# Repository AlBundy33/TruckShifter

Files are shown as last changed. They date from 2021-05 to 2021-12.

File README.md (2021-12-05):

# DIY real truck shifter

Because I'm playng Eurotruck Simulator 2 with my T300 + TH8A I wanted to have a shifter that has buttons for range and splitter.

Because I didn't want to spent over 100EUR for a simple gear stick with two or three buttons I decided to bought a cheap MAN shifter (81326200043) from china (in fact something about 16EUR on Amazon).

After that I've used my multimeter to find out the connections between the pins on the socket.

Later I had to open the shifter and could see the connections.

The TH8A uses an M9x1.25 thread and the shifter provides an M14x1.5 thread - unfortuately I didn't find an adapter to buy.

Luckily a forum-member offerd my to print this adapter from thingiverse.

https://www.thingiverse.com/thing:4827444

# Pinout

This is my numbering according to the colors on the plug.
```
0 (black)   1 (blue)    2 (two wires, green/yellow)
3 (purple)  4 (red)     5 (white)
```
ATTENTION: There is a resistor between red and white (range switch) which has to be removed.
To open the shifter you can carefully remove the plastic-piece (with the printed gears) with a plastic tool (just pull the plastic-piece backwards).

These are the connections between the pins
- comfort shift (top): 0 + 2 (normally closed), 1 + 2 (normally open), 1 + 3 (normally open, only if splitter is closed), 0 + 3 (normally closed, if splitter is closed)
- splitter (side): 2 (green)+ 3 (purple)
- range (front): 4 (red)+ 5 (white)

so i think the wiring could be done like this.
```
2 (green+yellow) + 4 (red) -> GND
1 (blue) -> PIN18 (comfort shift)
3 (purlple) -> PIN19 (splitter)
5 (white) -> PIN20 (range)
```

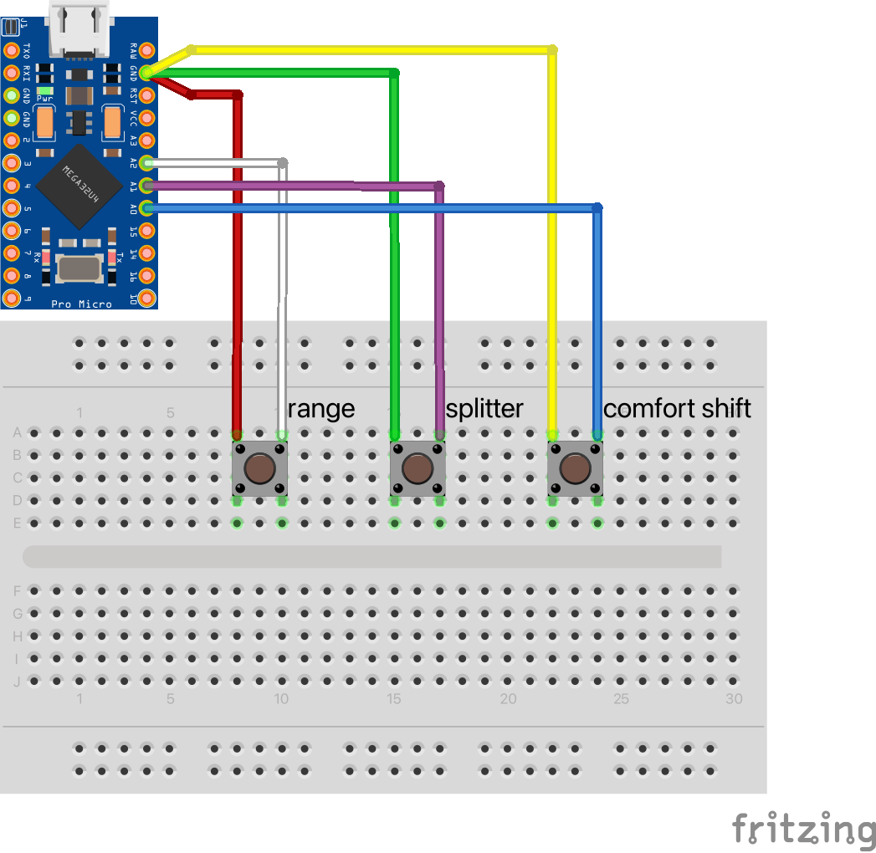
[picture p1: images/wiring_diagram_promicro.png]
wiring diagram (leonardo)

I'm using an arduino pro micro because it fits inside the shifter. :-)

You have to install this library in Arduino IDE: https://github.com/MHeironimus/ArduinoJoystickLibrary

# Pictures
open shifter
inside shifter 1
inside shifter 2
mounted pro micro

Because I have multiple USB devices I had to change the name of the usb device.

Therefore I've edited boards.txt from Arduino IDE and copied the complete block for leonardo.name=Arduino Leonardo

Then I've changed the IDs from "leonardo." to "leonardo_truckshifter." and the name and usb_product from "Arduino Leonardo" to "Arduino Leonardo (TruckShifter)".

As last step I've changed to VID to 0x2341 and the PID to 0xA001.

In the end it looks something like this.
-> This is only an example and for private use only because you have to pay for official/commercial VIDs and PIDs!!!!

HINT: Arduino IDE uses different boards.txt - one is located in your installation-folder under hardware\arduino\avr and the other under %LOCALAPPDATA%\Arduino15\packages\arduino\hardware\avr\1.8.4 (at least on windows - versions may change).

So if there is no "Arduino Leonardo (TruckShifter)" in your boards-list, make sure, that you have edited the correct boards.txt

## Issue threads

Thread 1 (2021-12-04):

Disable LED on pro micro

peer69, 2021-12-04:
By adding

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

to the setup block you can disable the lower LED of the pro micro. It bothered me seeing red light coming from the bottom of the shifter.
The power LED on the upper part cant be turned off in software though afaik, therefore I used some tape over the LED. Disabling the bottom LED and having the pro micro placed facing inwards the shifter might do the trick as well. I just didn't want to rewire it.

AlBundy33, 2021-12-04:
where did you get this information from?

peer69, 2021-12-04:
Been digging through some forum posts yesterday, probably from here: https://arduino.stackexchange.com/questions/3434/leonardo-disable-tx-and-rx-led

Tried it already, works well for me.

AlBundy33, 2021-12-04:
I'm not at the PC right now but have you tried just to call the mentioned macros?
```
TXLED0;
RXLED0;
```

peer69, 2021-12-04:
Yes, did nothing for me. Somebody mentioned this would work by selecting Arduino Micro as board but I haven't tried this after the method I mentioned did the trick. Not sure this is the "best" method to achieve this though.

AlBundy33, 2021-12-05:
in arduino_pins.h the macros are defined as
```
#define TX_RX_LED_INIT	DDRD |= (1<<5), DDRB |= (1<<0)
#define TXLED0			PORTD |= (1<<5)
#define TXLED1			PORTD &= ~(1<<5)
#define RXLED0			PORTB |= (1<<0)
#define RXLED1			PORTB &= ~(1<<0)
```
where TX_RX_LED_INIT sets them as output and your code sets them as input an therefore the LEDs are off.
I've accepted your PR and added some comments. 👍

Closed 2021-12-05.

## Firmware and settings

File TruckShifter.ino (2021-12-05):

#include <Arduino.h>
#include <Joystick.h>

// pins to use
#define COMFORT_SHIFT 18
#define SPLITTER      19
#define RANGE         20

// enable/disable debug-mode (serial output)
// #define DEBUG

// max time to be handled as short press
#define SHORT_PRESS   250

Joystick_ Joystick(JOYSTICK_DEFAULT_REPORT_ID,
                   JOYSTICK_TYPE_JOYSTICK, 4, 0,
                   false, false, false, false, false, false,
                   false, false, false, false, false);

unsigned long cs_press_time = 0L;

void setup() {
    // disable TX and RX LEDs
    // see https://arduino.stackexchange.com/questions/3434/leonardo-disable-tx-and-rx-led
    // and http://forum.arduino.cc/index.php?topic=145262.0
    // TX_RX_LED_INIT; // DDRD |= (1<<5), DDRB |= (1<<0)
    // it seems that TX_RX_LED_INIT makes PORTD5 and PORTB0 output pins
    // but we want to disable them and so we making them to inputs
    DDRD &= ~(1<<DDD5), DDRB &= ~(1<<DDB0);
    // set TX and RX pins to LOW
    TXLED0;
    RXLED0;
    pinMode(COMFORT_SHIFT, INPUT_PULLUP);
    pinMode(SPLITTER, INPUT_PULLUP);
    pinMode(RANGE, INPUT_PULLUP);
    #ifdef DEBUG
    Serial.begin(9600);
    #endif
    Joystick.begin();
}

void loop() {
    int cs = !digitalRead(COMFORT_SHIFT);
    int splitter = !digitalRead(SPLITTER);
    int range = !digitalRead(RANGE);
    unsigned long cs_pressed;

    if (cs == HIGH && cs_press_time == 0L)
        cs_press_time = millis();

    if (cs_press_time > 0)
      cs_pressed = millis() - cs_press_time;
    else
      cs_pressed = 0L;

    if (cs_pressed > SHORT_PRESS)
    {
      // hold / long press
      Joystick.setButton(1, HIGH);
    }
    else if (cs == LOW && cs_pressed > 0 && cs_pressed <= SHORT_PRESS)
    {
      // short press
      Joystick.setButton(0, HIGH);
      delay(100);
    }

    if (cs == LOW)
    {
      // reset comfort shift state
      cs_press_time = 0L;
      Joystick.setButton(0, LOW);
      Joystick.setButton(1, LOW);
    }

    Joystick.setButton(2, splitter);
    Joystick.setButton(3, range);

    #ifdef DEBUG
    Serial.print(cs);
    Serial.print("\t");
    Serial.print(splitter);
    Serial.print("\t");
    Serial.print(range);
    Serial.println();
    #endif
}

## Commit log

2021-04-19 Corrected thread values
2021-04-25 test sketch and first wiring diagram
    [wiring_diagram_leonardo.fzz]
2021-04-25 added resistor imfo
2021-05-01 working shifter
    [wiring_diagram_leonardo.fzz]
2021-05-01 updated image
    [wiring_diagram_leonardo.fzz]
2021-05-02 removed 100% NOT working debounce :-)
    [TruckShifter.ino]
2021-05-02 updated diagram for pro micro
    [wiring_diagram_leonardo.fzz, wiring_diagram_promicro.fzz]
2021-05-02 named button
    [wiring_diagram_promicro.fzz]
2021-05-02 smaller breadboard
    [wiring_diagram_promicro.fzz]
2021-05-02 change vid and pid
2021-05-04 double function (short an long press) for comfort shift
    [TruckShifter.ino]
2021-12-04 Disable bottom LED on pro micro
2021-12-05 added some hint for different boards.txt
2021-12-05 leonardo_truckshifter from boards.txt
